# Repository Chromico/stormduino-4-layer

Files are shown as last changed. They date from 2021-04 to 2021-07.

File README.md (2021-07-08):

# Stormduino 4 Layer Edition
An open source 4 layer arduino uno clone designed in KiCad in collaboration with tecknologg and cyberstorm.mu .The board uses the CH340C as the USB to serial converter and an Atmega328p (DIP) as the microcontroller. The board design and schematic is open source so do whatever you wish with it :)

My website: https://tecknologg.website

Blog post: https://link.tecknologg.website/yyaya

# Banner

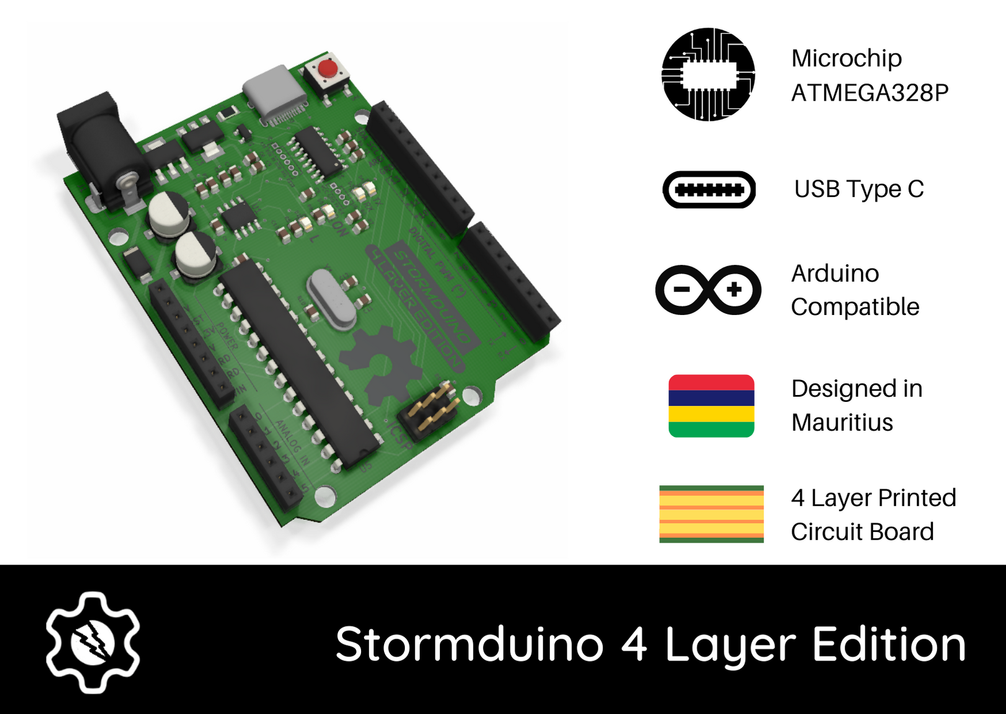
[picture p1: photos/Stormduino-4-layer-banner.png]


# Front 

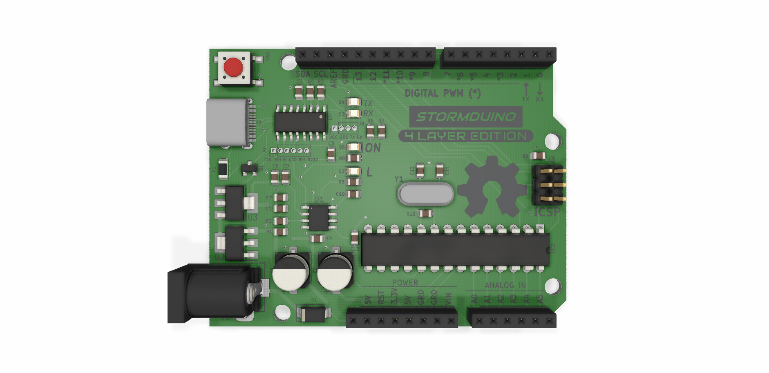
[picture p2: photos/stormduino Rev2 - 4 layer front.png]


# Back

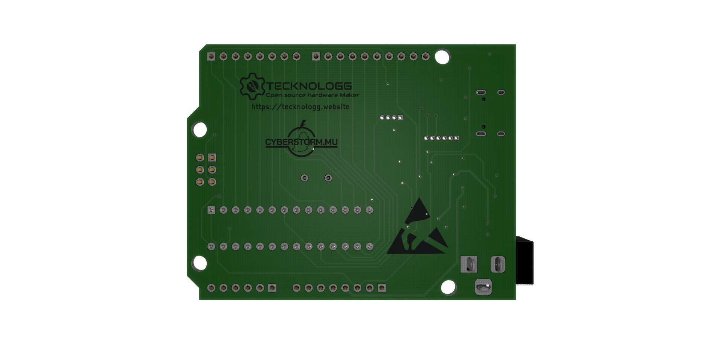
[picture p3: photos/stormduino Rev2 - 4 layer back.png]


# Assembled board

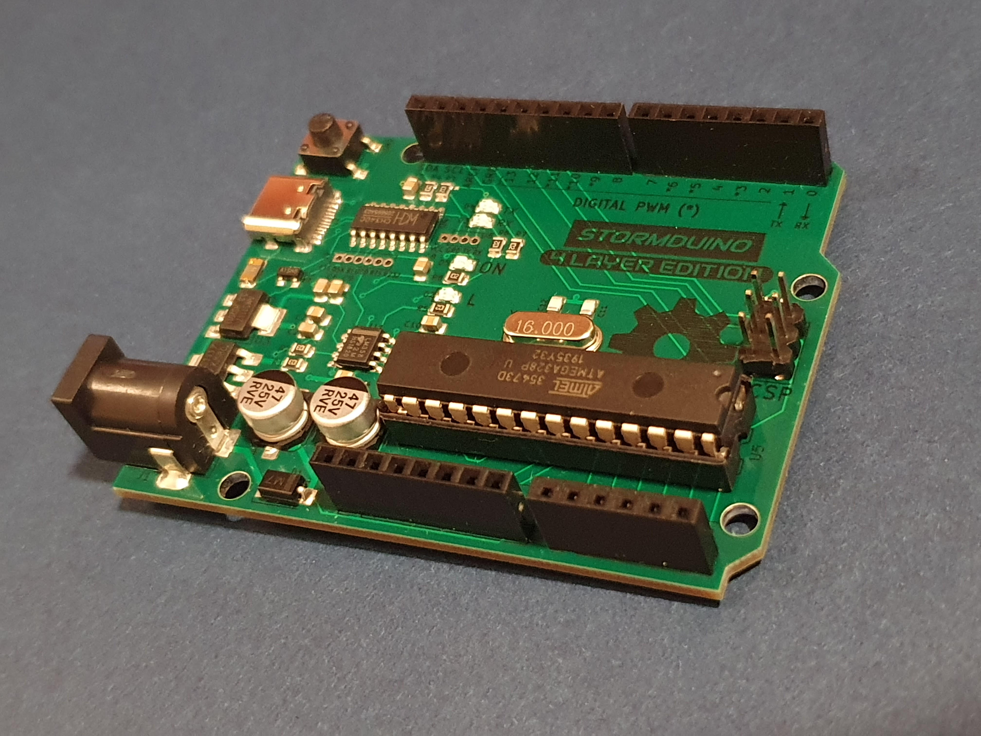
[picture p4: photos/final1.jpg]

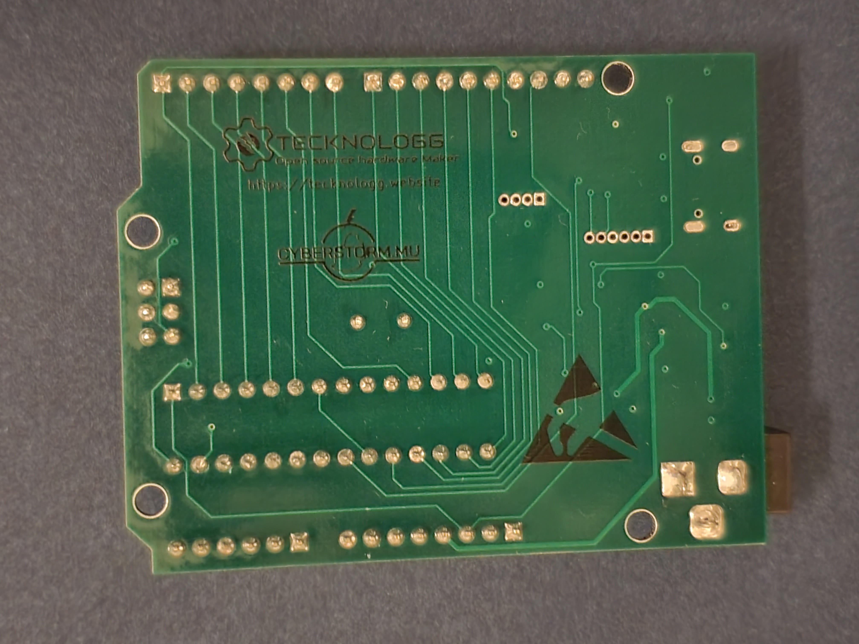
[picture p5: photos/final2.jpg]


# Documentation
You can get the official documentation here: https://github.com/Chromico/stormduino-4-layer/blob/main/documentation/Stormduino%204%20layer%20edition%20documentation.pdf

# Certification


# Contact

Need to contact me ? Just send me an email at nathan@tecknologg.website or tecknologg@gmail.com

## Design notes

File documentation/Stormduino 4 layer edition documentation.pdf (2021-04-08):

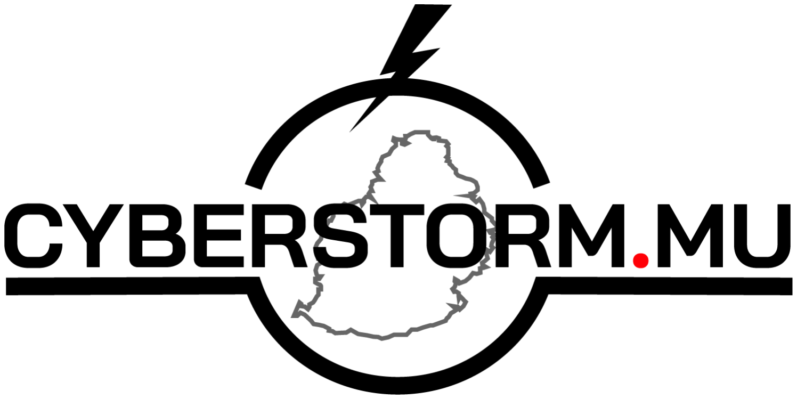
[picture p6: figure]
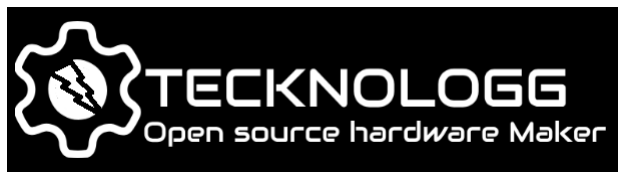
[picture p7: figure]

# Stormduino 4 Layer edition Documentation

April 8, 2021

# Project Overview

Stormduino is an Arduino compatible development that can be used in electronics projects and in STEM education. The project is open source hardware and designed with KiCad which makes it a lot easier for the user to modify.

The 4 Layer edition has an inner layer for +5V and another one for GRD. The top and bottom layer layout are very similar to the original stormduino however there are some slight changes to accommodate the two inner layers. The component layout remains the same to make the surface mount assembly process compatible with the previous version.

Project site where the design files and schematic can be found:

https://github.com/Chromico/stormduino-4-layer

Note: Please download the CH340 driver before using the board. You can get it here from the manufacturer’s website, http://www.wch.cn/downloads/CH341SER_EXE.html

# Assembled Board

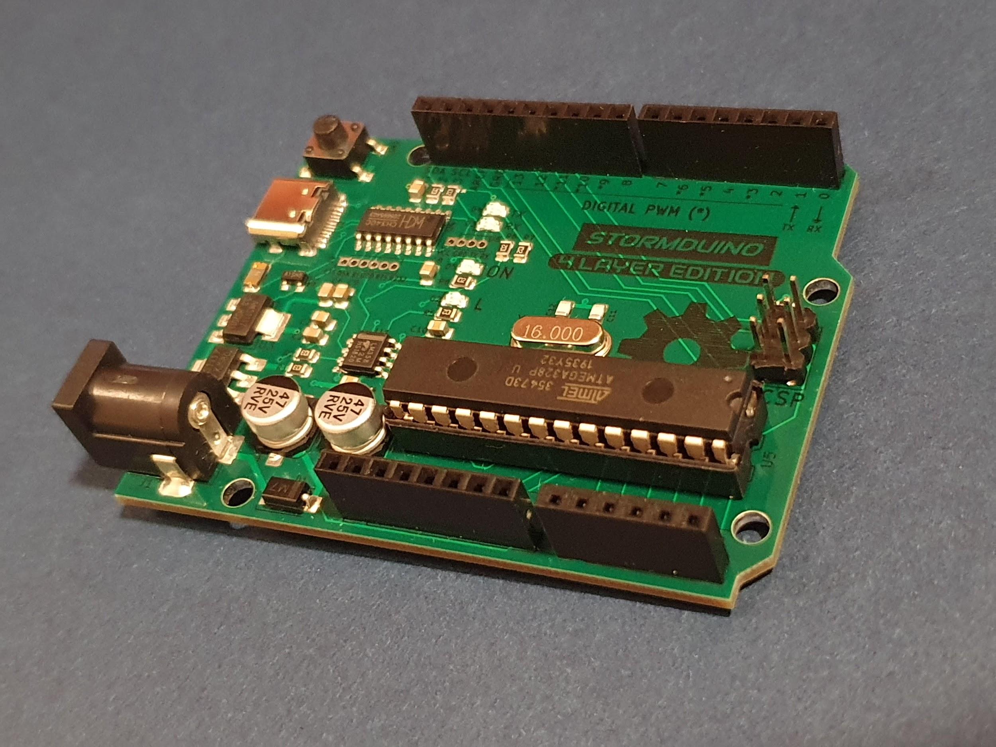
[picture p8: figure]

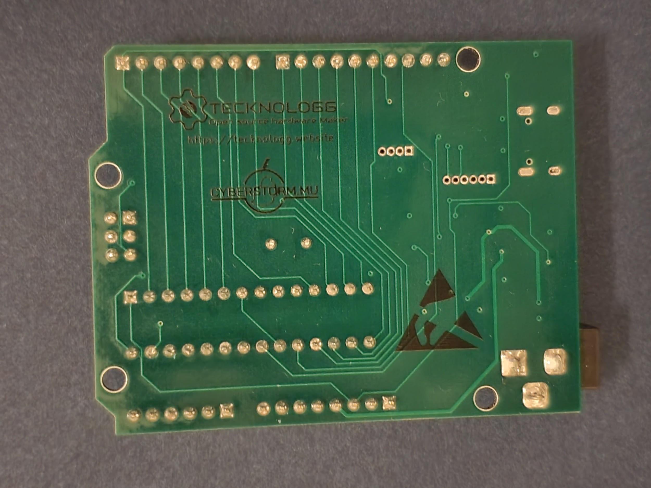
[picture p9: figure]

# Specifications

- Arduino bootloader
- 4 Layer Printed Circuit Board
- CH340C USB to UART bridge
- USB Type C connector for programming/communication
- Microchip AVR Atmega328P 16 Mhz ( external oscillator )
- 5V and 3.3V LDO regulators
- PCB size ( 54.34 mm x 68.58 mm )

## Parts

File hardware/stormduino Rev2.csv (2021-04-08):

Id | Designator | Package | Quantity | Designation | Supplier and ref
1 | J9 | PinHeader_1x06_P1.27mm_Vertical | 1 | Conn_01x06_MountingPin
2 | G*** | modern-dodos-3 | 1 | LOGO
3 | J8 | PinHeader_1x04_P1.27mm_Vertical | 1 | Conn_01x04_MountingPin
4 | C2 | CP_Elec_6.3x5.4 | 1 | 10uF
5 | C1 | CP_Elec_6.3x5.4 | 1 | 47uF
6 | Y1 | Resonator-2Pin_W10.0mm_H5.0mm | 1 | 16 Mhz
7 | REF** | OSHW-Logo2_14.6x12mm_SilkScreen | 1 | OSHW-Logo2_14.6x12mm_SilkScreen
8 | G*** | tecknologg7 | 1 | LOGO
9 | D1 | D_SMA | 1 | DIODE
10 | F1 | C_1206_3216Metric | 1 | Fuse
11 | R10 | C_0805_2012Metric | 1 | 1M
12 | R9 | C_0805_2012Metric | 1 | 1K
13 | R8,R4,R5,R6,R3,R7 | C_0805_2012Metric | 6 | 1k
14 | J2 | USB_C_Receptacle_HRO_TYPE-C-31-M-12 | 1 | USB_C_Receptacle_USB2.0
15 | J3 | PinHeader_2x03_P2.54mm_Vertical | 1 | Conn_02x03_Odd_Even
16 | U5 | DIP-28_W7.62mm | 1 | ATmega328P-PU
17 | G*** | minicyberstorm3 | 1 | LOGO
18 | C12,C11 | C_0805_2012Metric | 2 | 22pF
19 | D5,D2,D3,D4 | LED_0805_2012Metric | 4 | LED
20 | U4 | SOIC-16_3.9x9.9mm_P1.27mm | 1 | CH340C
21 | R2,R1 | C_0805_2012Metric | 2 | 10k
22 | C10,C13,C9,C4,C7,C3 | C_0805_2012Metric | 6 | 100nF
23 | C8 | C_0805_2012Metric | 1 | 100nf
24 | C6,C2 | C_0805_2012Metric | 2 | 10uF
25 | Q1 | SOT-23 | 1 | BS250
26 | U1 | SOP-8_3.76x4.96mm_P1.27mm | 1 | LM358
27 | SW1 | SW_SPST_B3S-1000 | 1 | SW_Push
28 | J1 | BarrelJack_Horizontal | 1 | Jack-DC
29 | J5,J7 | PinHeader_1x08_P2.54mm_Vertical | 2 | Conn_01x08_MountingPin
30 | J6 | PinHeader_1x10_P2.54mm_Vertical | 1 | Conn_01x10_MountingPin
31 | J4 | PinHeader_1x06_P2.54mm_Vertical | 1 | Conn_01x06_MountingPin
32 | U2 | SOT-223-3_TabPin2 | 1 | AMS1117-5.0
33 | U3 | SOT-223-3_TabPin2 | 1 | AMS1117-3.3
34 | G*** | stormduino5 | 1 | LOGO

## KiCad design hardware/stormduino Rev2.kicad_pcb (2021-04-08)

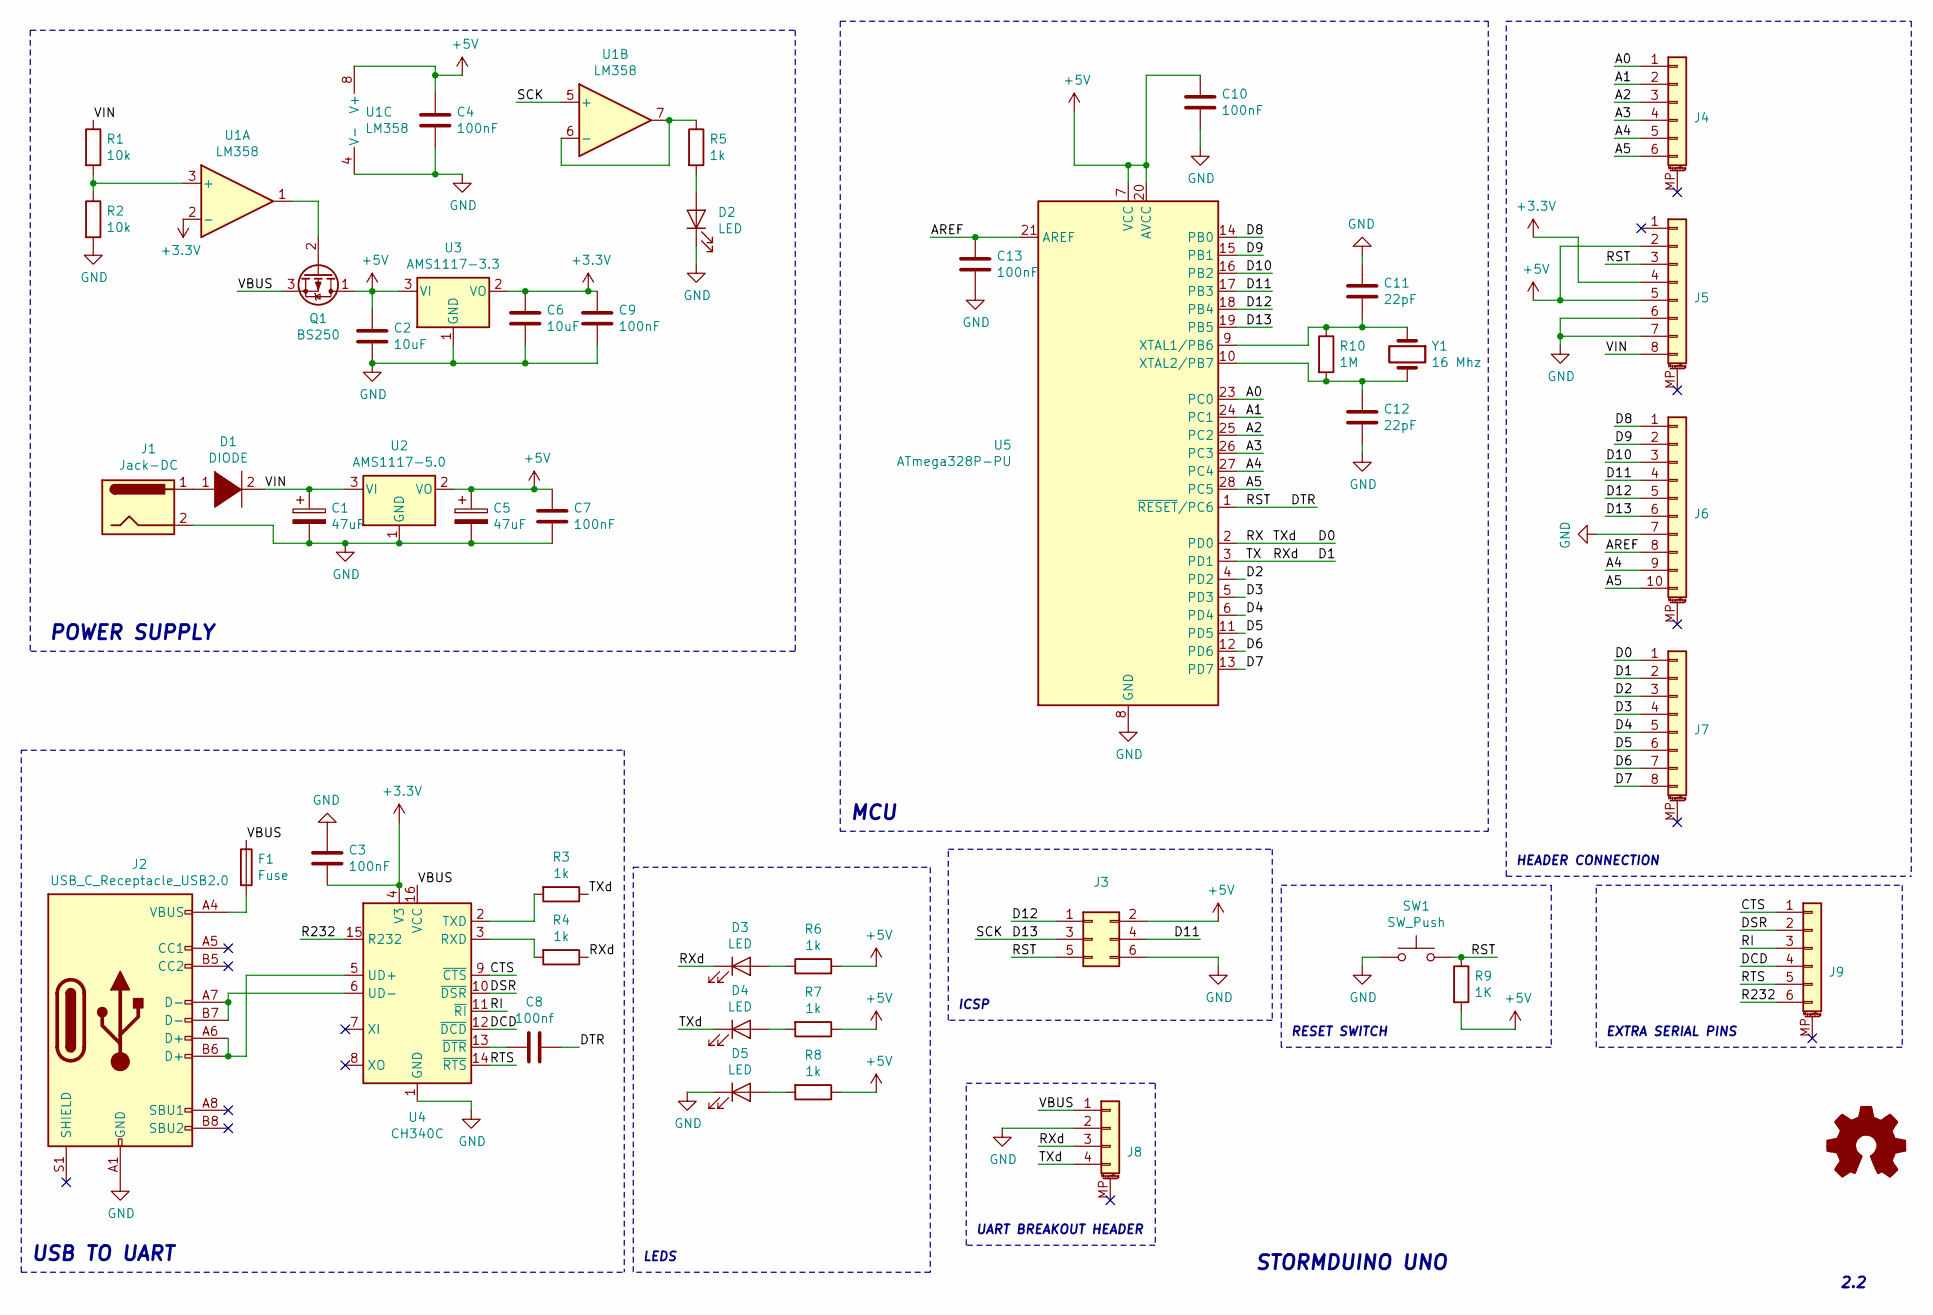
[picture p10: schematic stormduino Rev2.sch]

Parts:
C1, C5: 47uF
C2, C6: 10uF
C3, C4, C7, C9, C10, C13: 100nF
C8: 100nf
C11, C12: 22pF
D1: DIODE
D2, D3, D4, D5: LED
F1: Fuse
J1: Jack-DC
J2: USB_C_Receptacle_USB2.0
J3: Conn_02x03_Odd_Even
J4, J9: Conn_01x06_MountingPin
J5, J7: Conn_01x08_MountingPin
J6: Conn_01x10_MountingPin
J8: Conn_01x04_MountingPin
Q1: BS250; TO-92_Inline
R1, R2: 10k
R3, R4, R5, R6, R7, R8: 1k
R9: 1K
R10: 1M
SW1: SW_Push
U1: LM358
U2: AMS1117-5.0; SOT-223-3_TabPin2
U3: AMS1117-3.3; SOT-223-3_TabPin2
U4: CH340C; SOIC-16_3.9x9.9mm_P1.27mm
U5: ATmega328P-PU; DIP-28_W7.62mm
Y1: 16 Mhz

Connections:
+3V3: C3.2, C6.1, C9.1, J5.4, U1.2 (-), U3.2 (VO), U4.4 (V3)
/A0: J4.1, U5.23 (PC0)
/A1: J4.2, U5.24 (PC1)
/A2: J4.3, U5.25 (PC2)
/A3: J4.4, U5.26 (PC3)
/A4: J4.5, J6.9, U5.27 (PC4)
/A5: J4.6, J6.10, U5.28 (PC5)
/AREF: C13.1, J6.8, U5.21 (AREF)
/CTS: J9.1, U4.9 (~CTS)
/D0: D4.1 (K), J7.1, J8.4, R3.1, U5.2 (PD0)
/D1: D3.1 (K), J7.2, J8.3, R4.1, U5.3 (PD1)
/D2: J7.3, U5.4 (PD2)
/D3: J7.4, U5.5 (PD3)
/D4: J7.5, U5.6 (PD4)
/D5: J7.6, U5.11 (PD5)
/D6: J7.7, U5.12 (PD6)
/D7: J7.8, U5.13 (PD7)
/D8: J6.1, U5.14 (PB0)
/D9: J6.2, U5.15 (PB1)
/D10: J6.3, U5.16 (PB2)
/D11: J3.4, J6.4, U5.17 (PB3)
/D12: J3.1, J6.5, U5.18 (PB4)
/D13: J3.3, J6.6, U1.5 (+), U5.19 (PB5)
/DCD: J9.4, U4.12 (~DCD)
/DSR: J9.2, U4.10 (~DSR)
/DTR: C8.1, J3.5, J5.3, R9.1, SW1.2, U5.1 (~RESET~/PC6)
/R232: J9.6, U4.15 (R232)
/RI: J9.3, U4.11 (~RI)
/RTS: J9.5, U4.14 (~RTS)
/VBUS: F1.1, J8.1, Q1.3 (S), U4.16 (VCC)
/VIN: C1.1, D1.2 (A), J5.8, R1.1, U2.3 (VI)
GND: C1.2, C2.2, C3.1, C4.2, C5.2, C6.2, C7.2, C9.2, C10.2, C11.1, C12.2, C13.2, D2.1 (K), D5.1 (K), J1.2, J2.A1 (GND), J2.A12 (GND), J2.B1 (GND), J2.B12 (GND), J3.6, J5.6, J5.7, J6.7, J8.2, R2.2, SW1.1, U1.4 (V-), U2.1 (GND), U3.1 (GND), U4.1 (GND), U5.8 (GND), U5.22 (GND); also elsewhere on the board
unnamed: C8.2, U4.13 (~DTR)
unnamed: C11.2, R10.1, U5.9 (XTAL1/PB6), Y1.1
unnamed: C12.1, R10.2, U5.10 (XTAL2/PB7), Y1.2
unnamed: D1.1 (K), J1.1
unnamed: D2.2 (A), R5.2
unnamed: D3.2 (A), R6.1
unnamed: D4.2 (A), R7.2
unnamed: D5.2 (A), R8.2
unnamed: F1.2, J2.A4 (VBUS), J2.A9 (VBUS), J2.B4 (VBUS), J2.B9 (VBUS)
unnamed: J2.A6 (D+), J2.B6 (D+), U4.5 (UD+)
unnamed: J2.A7 (D-), J2.B7 (D-), U4.6 (UD-)
unnamed: R1.2, R2.1, U1.3 (+)
unnamed: R3.2, U4.2 (TXD)
unnamed: R4.2, U4.3 (RXD)
unnamed: R5.1, U1.6 (-), U1.7

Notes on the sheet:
POWER SUPPLY
USB TO UART
MCU
STORMDUINO UNO
2.2
ICSP
HEADER CONNECTION
LEDS
RESET SWITCH
UART BREAKOUT HEADER
EXTRA SERIAL PINS

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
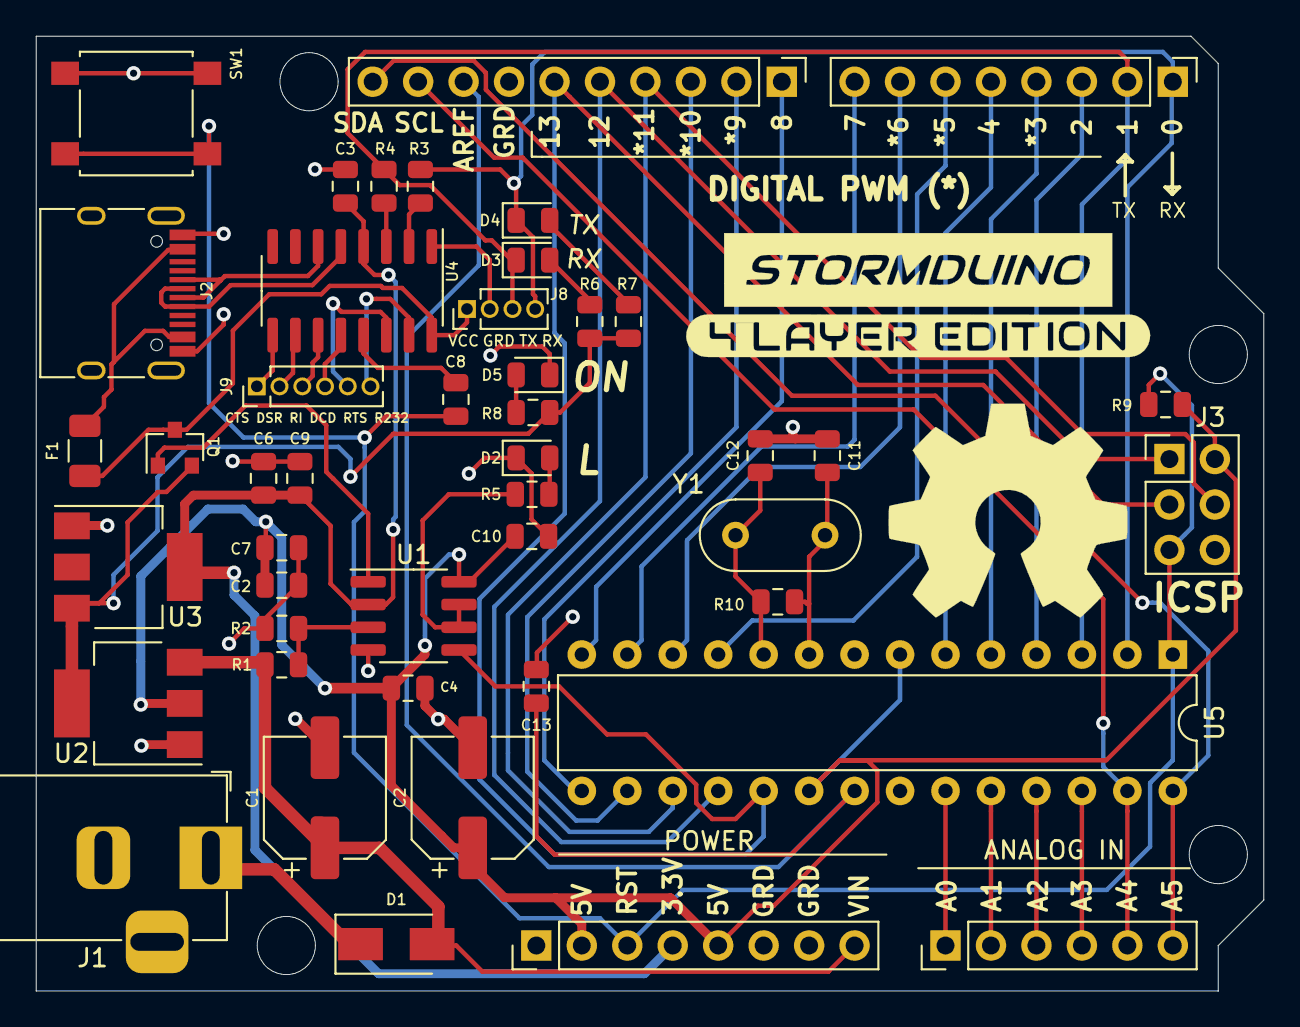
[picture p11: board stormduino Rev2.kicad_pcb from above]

Board: 4 copper layers, 68.6 x 53.3 mm, 46 parts (0 on the bottom side), 49 nets.

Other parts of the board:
C2#2: 10uF; C_0805_2012Metric

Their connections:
GND: C2#2.2; also elsewhere on the board
